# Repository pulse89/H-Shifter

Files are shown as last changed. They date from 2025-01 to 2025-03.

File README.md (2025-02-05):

# H-Pattern and Sequential Shifter

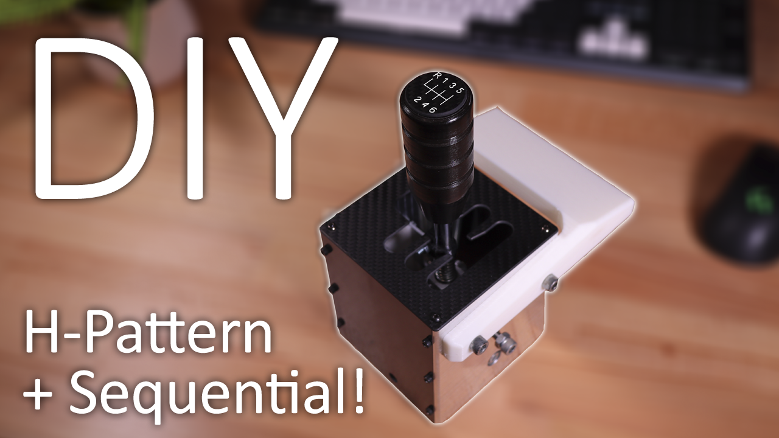
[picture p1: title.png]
H-Shifter


Link to the video: [https://youtu.be/RtLBD2DWTTg](https://youtu.be/AKZnvJ_tqVI)

I got sick of using the flappy paddles on my Logitech wheel so I decided to build my own H-Pattern and sequential shifter! All parts can be 3D printed!

I've included all the files in both STEP and STL format. If you decide to have the internals made in Aluminium like I did in the video, use the "Bearing Mount Alloy.STEP" file instead of the "Printed Bearing Block.STL".

You will also need to purchase the following parts:

2x 625 Bearings - https://www.aliexpress.com/item/1005004857666772.html

2x R4 Bearings - https://www.aliexpress.com/item/32929910901.html

4x 623 Bearings - https://www.aliexpress.com/item/1005004857666772.html

1x 10k 16mm Linear Potentiometer - https://www.aliexpress.com/item/1005006600576995.html

2x Micro Lever Switches (Handle 11.5mm) - https://www.aliexpress.com/item/1005005596552328.html

5mm Steel Ball - https://www.aliexpress.com/item/1005005656499702.html

4mm OD Spring - https://www.aliexpress.com/item/1005005402716572.html

13x30x1.4 Spring - https://www.aliexpress.com/item/1005006145869116.html

10x30x1 Extension Spring - https://www.aliexpress.com/item/1005006138122733.html

1x Arduino Pro Micro - https://www.aliexpress.com/item/1005006654641959.html

1x 10x140mm Hardened Steel Shaft - https://www.aliexpress.com/item/1005007573838689.html

If printing, you will also need:
16x M3x5x5 Threaded Inserts
2x M3x4x5 Threaded Inserts

You'll also need a variety of M3 screws, nuts and washers along with a couple of M5 washers for spacing out the bearings as shown in the video.

#### Electronics and Software

Wire the potentiometer output to A3, and the switches to D2 and D3.

When you first flash the code to your Arduino, change the debug variable to true and check the serial port for readings from your potentiometer. Copy values from each gate into the correct variables and then re-upload the code and verify the correct gears are being selected. Then change debug back to false and re-upload!

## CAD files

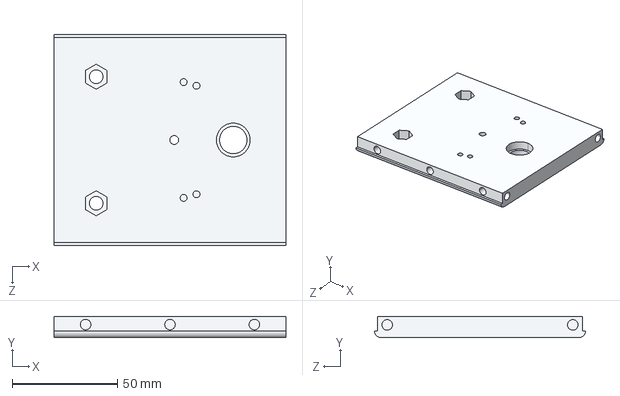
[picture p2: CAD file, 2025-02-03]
3D Files/STEP/Housing Side 2.STEP
110.0 x 10.0 x 100.0 mm

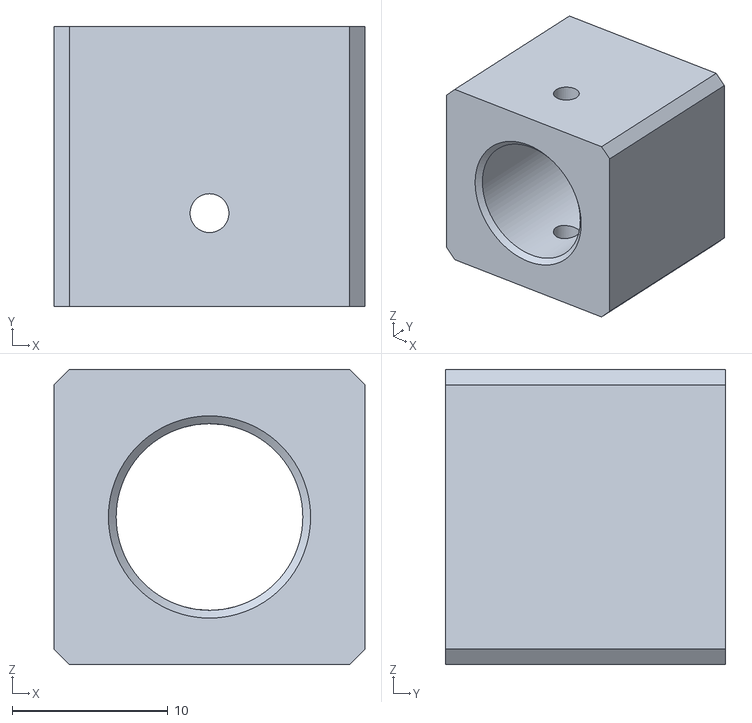
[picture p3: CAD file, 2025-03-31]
3D Files/STL/Bearing Mount Alloy v2.STL
20.0 x 18.0 x 19.0

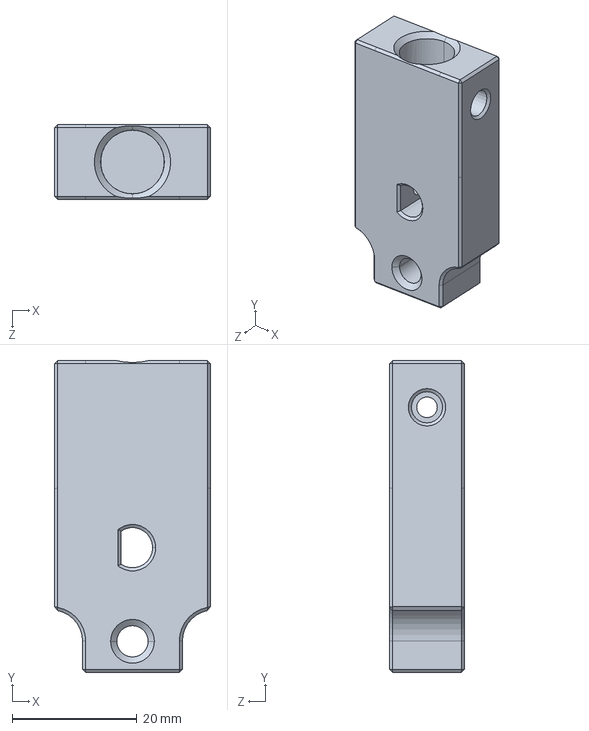
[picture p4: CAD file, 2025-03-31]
3D Files/SW/Shaft Pivot 3D Print.SLDPRT
25.0 x 50.0 x 12.0 mm

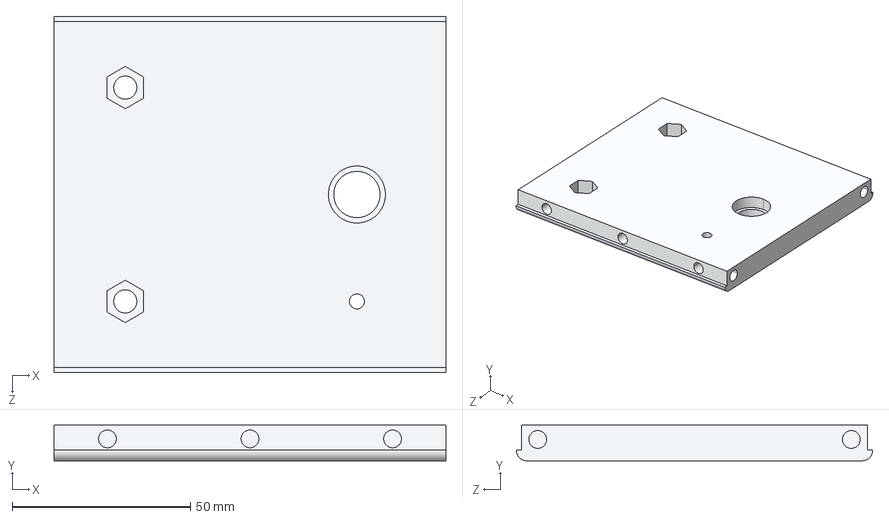
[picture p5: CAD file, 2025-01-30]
3D Files/STEP/Housing Side 1.STEP
110.0 x 10.0 x 100.0 mm

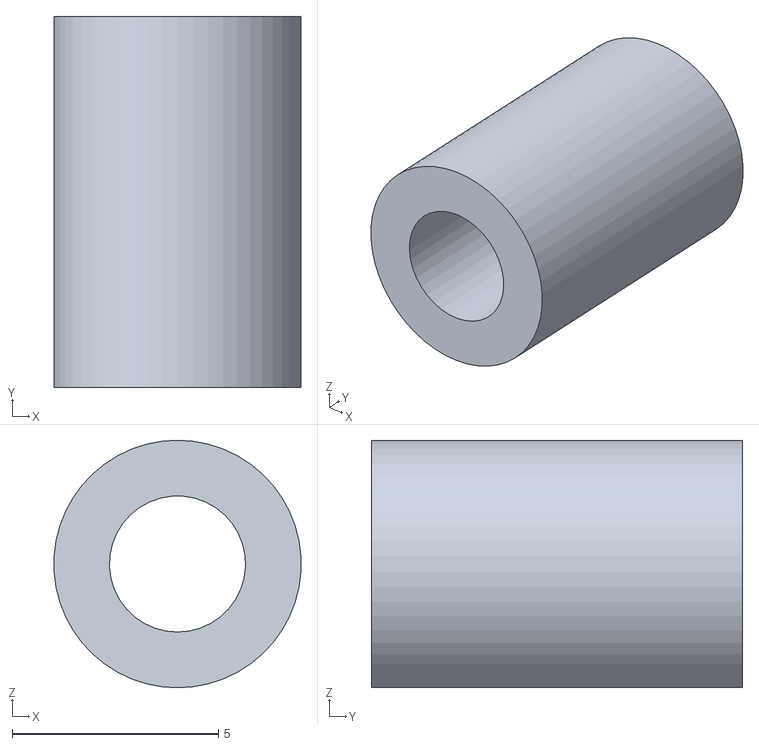
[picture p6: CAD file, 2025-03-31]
3D Files/STL/Spring Arm Spacer.STL
5.99 x 9.00 x 6.00

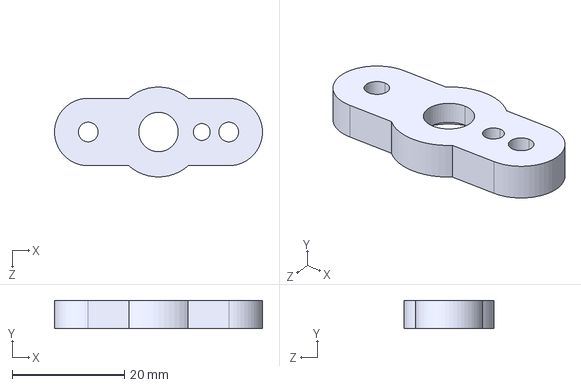
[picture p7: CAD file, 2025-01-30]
3D Files/STEP/Pot Mount.STEP
37.0 x 5.00 x 16.0 mm

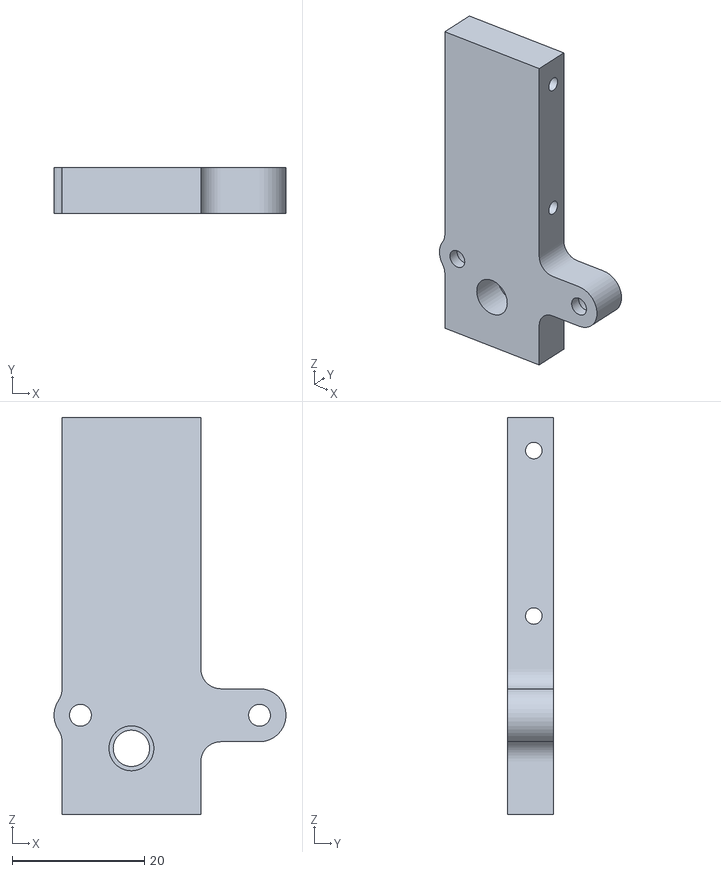
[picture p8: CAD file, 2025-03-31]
3D Files/STL/Shifter Spring End Plate v2.STL
35.0 x 7.00 x 60.0

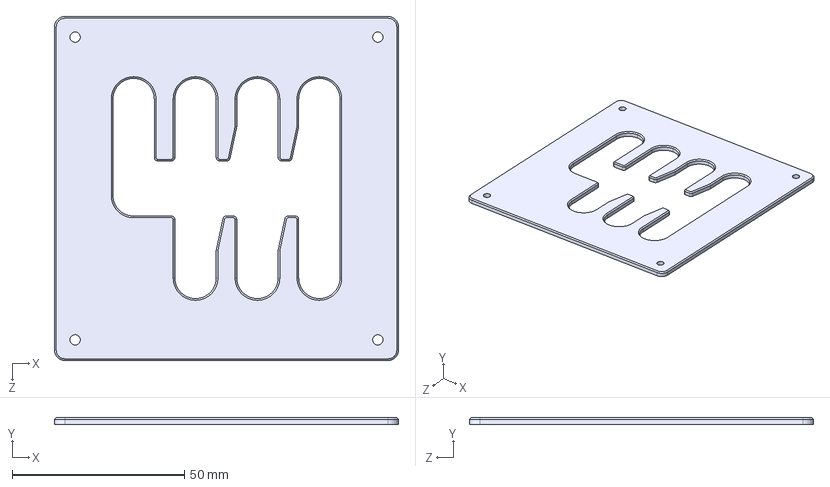
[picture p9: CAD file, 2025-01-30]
3D Files/STEP/Shifter Top Plate.STEP
100.0 x 2.00 x 100.0 mm

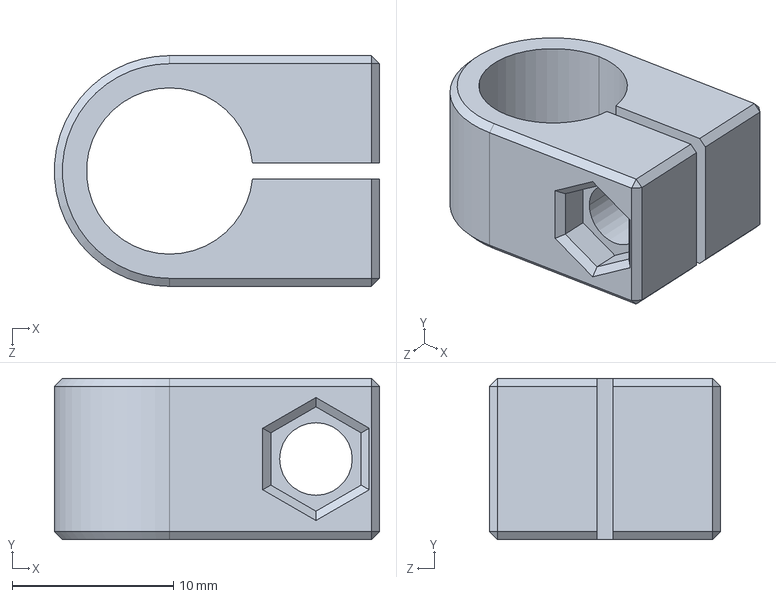
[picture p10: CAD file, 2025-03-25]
3D Files/SW/Shaft Clamp.SLDPRT
20.1 x 10.0 x 14.3 mm

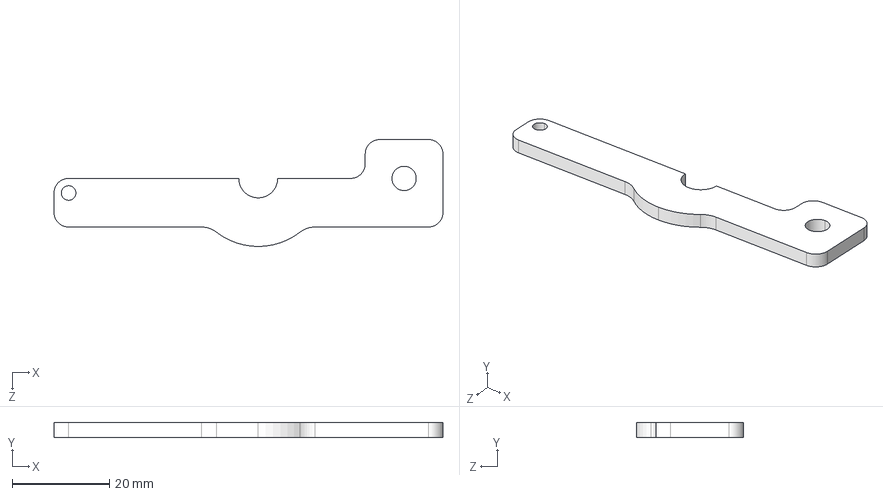
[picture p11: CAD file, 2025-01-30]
3D Files/STEP/Spring Arm.STEP
80.0 x 3.00 x 22.0 mm

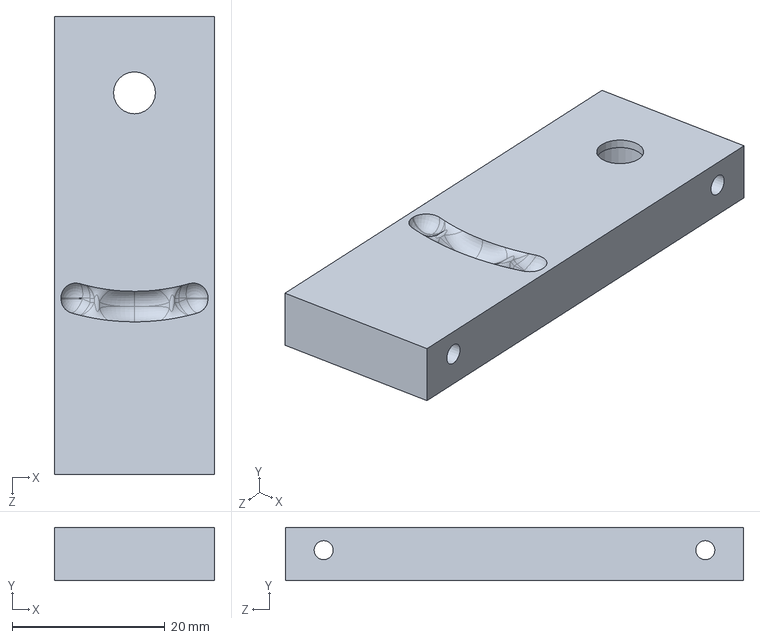
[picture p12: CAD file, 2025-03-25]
3D Files/SW/Shifter End Plate.SLDPRT
21.0 x 7.00 x 60.0 mm

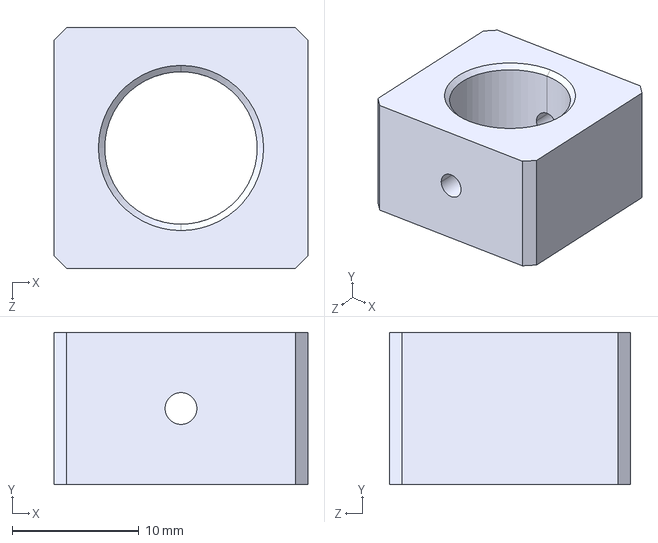
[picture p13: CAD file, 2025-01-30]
3D Files/STEP/Bearing Mount Alloy.STEP
20.0 x 12.0 x 19.0 mm

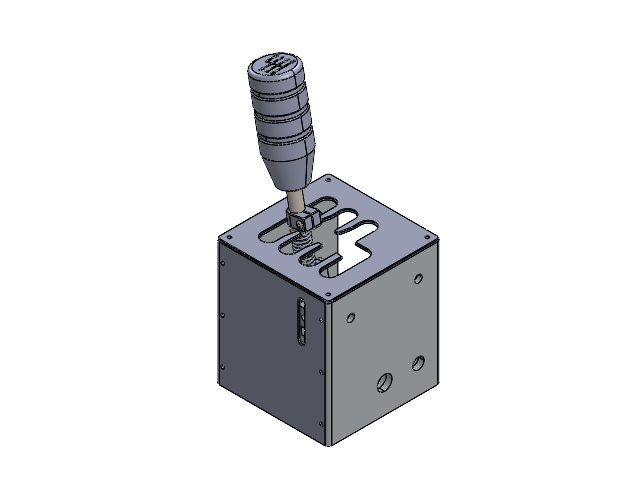
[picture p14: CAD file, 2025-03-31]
3D Files/Shifter Main Assembly.SLDASM
Housing Rear
Housing Side 1
Housing Side 2
Pot Mount
Bearing Mount 3D Printed
Shaft Clamp
Shifter Side Plate 1
Shifter Side Plate 2
Shifter Spring End Plate
Shaft Pivot 3D Print
Shifter End Plate
Shaft
623 Bearing x 2
Shifter Spring
R4ZZ Bearing x 2
R1212N_D-Shaft
Shaft Pivot Washer x 4
ISO 7380 - M3 x 16 - 16N
ISO - 4034 - M3 - N
Shifter Knob
Shifter Top Plate
Spring Arm
Spring Tensioner
Spring Arm Spacer

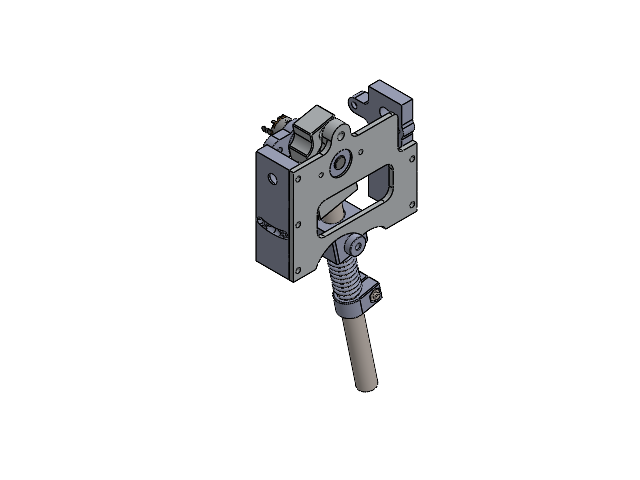
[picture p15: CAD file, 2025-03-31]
3D Files/Shifter Centre Assembly.SLDASM
Pot Mount
Bearing Mount 3D Printed
Shaft Clamp
Shifter Side Plate 1
Shifter Spring End Plate
Shaft Pivot 3D Print
Shifter End Plate
Shaft
623 Bearing x 2
Shifter Spring
R4ZZ Bearing x 2
R1212N_D-Shaft
Shaft Pivot Washer x 2
ISO 7380 - M3 x 16 - 16N
ISO - 4034 - M3 - N

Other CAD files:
3D Files/SW/Bearing Mount Alloy.SLDPRT
3D Files/SW/Bearing Mount 3D Printed.SLDPRT
3D Files/STL/Shaft Pivot 3D Print.STL
3D Files/STL/Bearing Mount 3D Printed.STL
3D Files/STEP/Desk Mount.STEP
3D Files/STEP/Housing Front.STEP
3D Files/STEP/Housing Rear.STEP
3D Files/STEP/Shaft Clamp.STEP
3D Files/STEP/Shaft Pivot.STEP
3D Files/STEP/Shifter End Plate.STEP
3D Files/STEP/Shifter Knob.STEP
3D Files/STEP/Shifter Side Plate 1.STEP
3D Files/STEP/Shifter Side Plate 2.STEP
3D Files/STEP/Shifter Spring End Plate.STEP
3D Files/STEP/Spring Tensioner.STEP
3D Files/STL/Desk Mount.STL
3D Files/STL/Housing Front.STL
3D Files/STL/Housing Rear.STL
3D Files/STL/Housing Side 1.STL
3D Files/STL/Housing Side 2.STL
3D Files/STL/PETG Bushing.STL
3D Files/STL/Pot Mount.STL
3D Files/STL/Printed Bearing Block.STL
3D Files/STL/Shaft Clamp v2.STL
3D Files/STL/Shaft Clamp.STL
3D Files/STL/Shaft Pivot Washer.STL
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

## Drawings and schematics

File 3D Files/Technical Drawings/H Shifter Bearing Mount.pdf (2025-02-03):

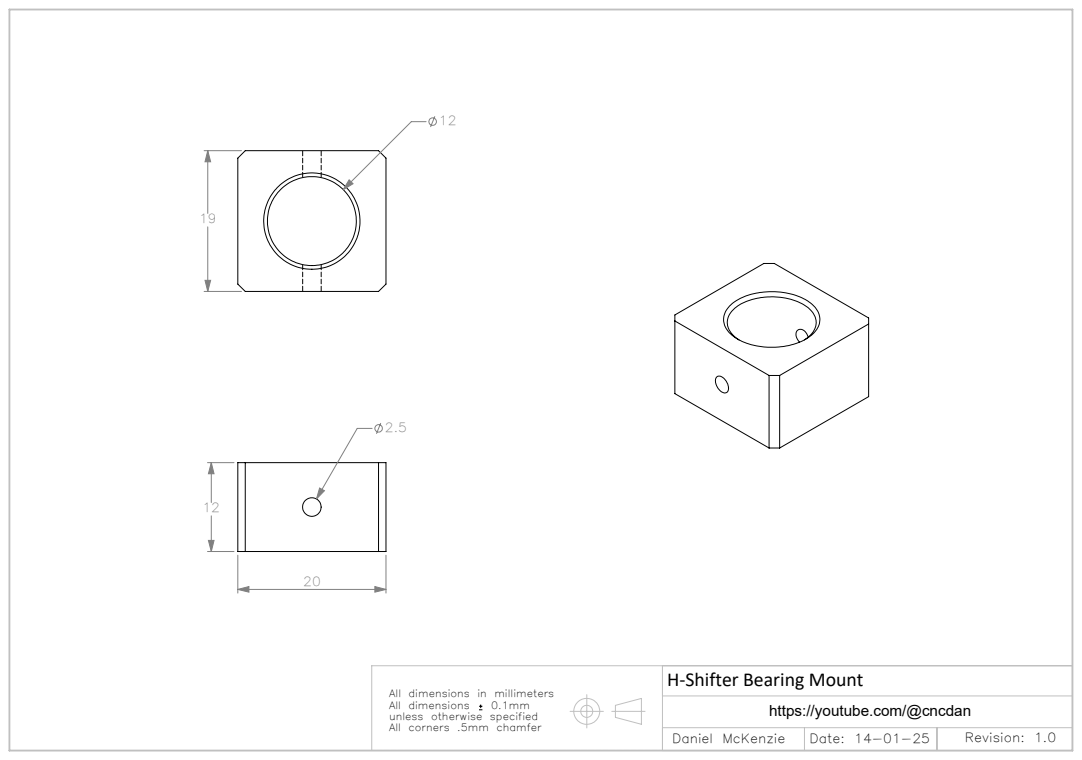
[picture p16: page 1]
Daniel McKenzie; Date: 14-01-25; Revision: 1.0; All dimensions

H-Shifter Bearing Mount

All dimensions in millimeters
unless otherwise specified
All corners .5mm chamfer

https://youtube.com/@cncdan

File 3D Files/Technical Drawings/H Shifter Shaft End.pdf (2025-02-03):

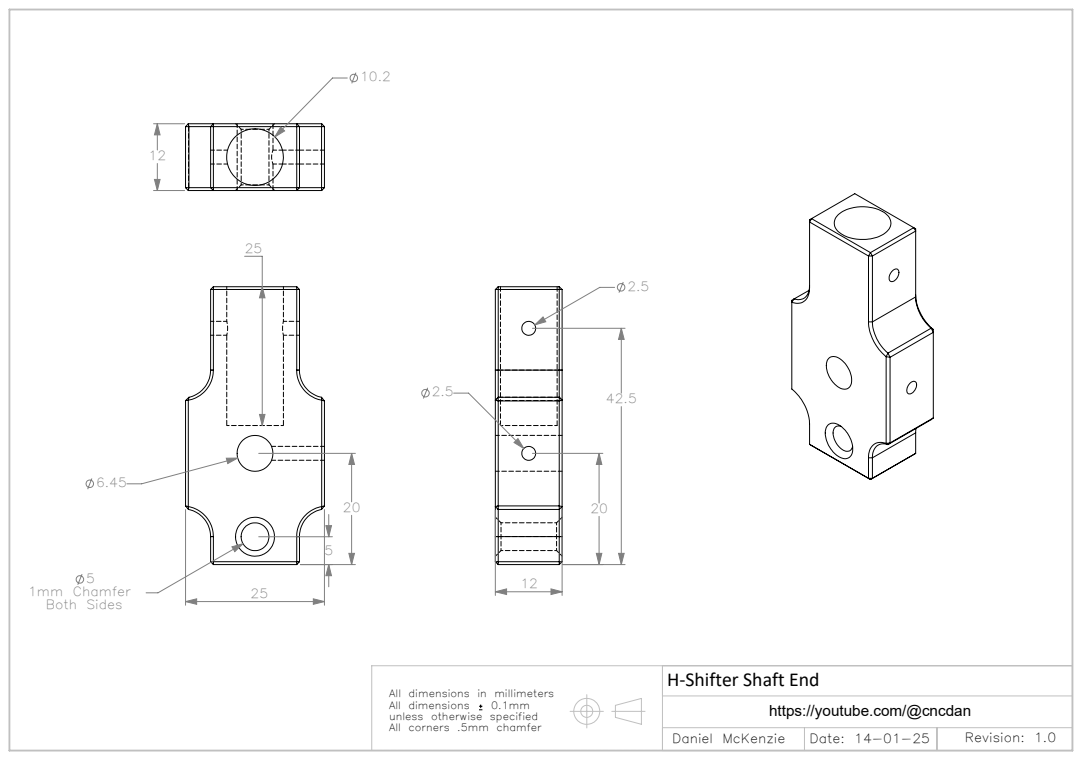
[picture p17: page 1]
1mm Chamfer Both Sides; Daniel McKenzie; Date: 14-01-25; Revision: 1.0; All dimensions

H-Shifter Shaft End

All dimensions in millimeters
unless otherwise specified
All corners .5mm chamfer

https://youtube.com/@cncdan

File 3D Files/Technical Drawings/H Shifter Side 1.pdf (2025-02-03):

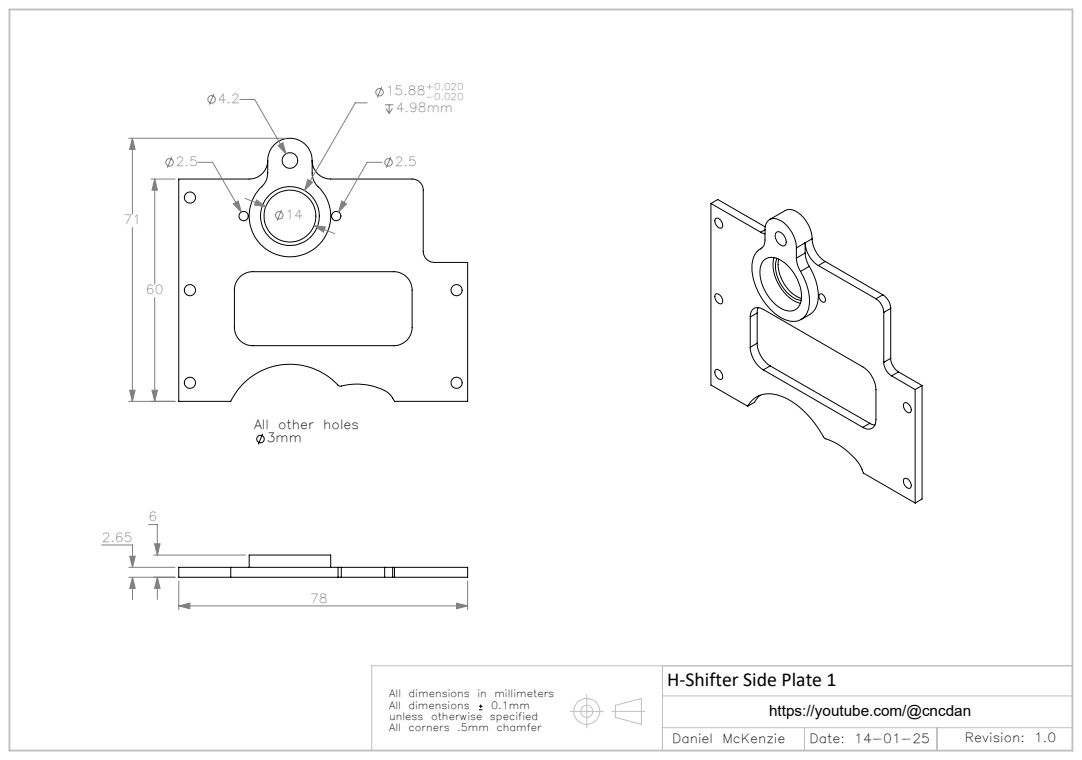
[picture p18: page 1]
Daniel McKenzie; Date: 14-01-25; Revision: 1.0; All dimensions

All other holes

H-Shifter Side Plate 1

All dimensions in millimeters
unless otherwise specified
All corners .5mm chamfer

https://youtube.com/@cncdan

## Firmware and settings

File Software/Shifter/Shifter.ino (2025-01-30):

#include "HID-Project.h"

int gearUp = 2; //Pin 2 for top row of gears
int gearDn = 3; //Pin 3 for bottom row of gears

//Change these values to match the values shown in debug for each gate.
int gateR = 222;
int gate12 = 183;
int gate34 = 145;
int gate56 = 106;

int gateDeadband = 10; //Adjust higher if analog signal is too noisey

int gateSelected;

int currentGear = 0;

bool debug = false; //Set to true to output potentiometer value and gear selected over serial.

void setup() {
  if(debug){
    Serial.begin(9600);
  }
  pinMode(gearUp, INPUT_PULLUP);
  pinMode(gearDn, INPUT_PULLUP);

  Gamepad.begin();
}

void loop() {
  gateSelected = analogRead(A3); //Read Potentiometer

  if(!digitalRead(gearUp)){ //Reverse,First,Third or fifth selected
    if(gateSelected < gate56 + gateDeadband){
      Gamepad.press(5);
      currentGear = 5;
    } else if(gateSelected < gate34 + gateDeadband && gateSelected > gate34 - gateDeadband){
      Gamepad.press(3);
      currentGear = 3;
    } else if(gateSelected < gate12 + gateDeadband && gateSelected > gate12 - gateDeadband){
      Gamepad.press(1);
      currentGear = 1;
    } else if(gateSelected < gateR + gateDeadband && gateSelected > gateR - gateDeadband){
      Gamepad.press(7);
      currentGear = 7;
    }
  } else if(!digitalRead(gearDn)){ //Second, fourth or sixth selected
    if(gateSelected < gate56 + gateDeadband){
      Gamepad.press(6);
      currentGear = 6;
    } else if(gateSelected < gate34 + gateDeadband && gateSelected > gate34 - gateDeadband){
      Gamepad.press(4);
      currentGear = 4;
    } else if(gateSelected < gate12 + gateDeadband && gateSelected > gate12 - gateDeadband){
      Gamepad.press(2);
      currentGear = 2;
    } 
  } else {
    Gamepad.releaseAll();
  }

  if(debug){
    Serial.print("Current Potentiometer Value: ");
    Serial.println(gateSelected);
    Serial.print("Gear Selected: ");
    Serial.println(currentGear);
  }

  Gamepad.write();
}

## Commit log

2025-01-30 Added 3D files
    [Bearing Mount Alloy.STEP, Desk Mount.STEP, Desk Mount.STL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]
2025-02-03 Update Housing Side 2.STL
    [Housing Side 2.STL]
2025-02-03 Update Housing Side 2.STEP
    [Housing Side 2.STEP]
2025-03-24 Added Assembly
    Converted STP files to SW Part files
    Added Bearing models
    Added Main Spring model
    Added 10k Pot model
    TODO: Add tensionerspring
    TODO: Add microswitches
    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
    [623 Bearing.SLDPRT, Bearing Mount Alloy.SLDPRT, Housing Front.SLDPRT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]
2025-03-25 Updates to various
    Bearing Mount - Added 6 mm in height to prevent catching when at maximum
    Shaft Clamp - made cut out for M3 nut, remove need to use nut driver
    Shaft Pivot - Added 3D printed version; added material for d-shaft, no longer relying solely on lock screw to rotate pot shaft, added chamfers on screw holes (I was using self-tapping screws, makes it easier to start the threads)
    Shifter End Plate - Expanded M5 hole to be able to use threaded inserts (also added 1 mm material and then a 1 mm thick hard stop), changes mounting holes to DIA2.5 mm to accommodate self tapping screws
    Shifter Spring End Plate - Expanded M5 hole to be able to use threaded inserts (also added 1 mm materi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
    [Bearing Mount Alloy.SLDPRT, Shaft Clamp.SLDPRT, Shaft Pivot 3D Print.SLDPRT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]
2025-03-31 Mods
    Bearing Mount 3D Printed - Added length to the 3D printed version
    Shaft Pivot 3D Print - Added material to use threaded inserts, opened up D-shaft hole
    [Bearing Mount 3D Printed.SLDPRT, Bearing Mount 3D Printed.STL, Bearing Mount Alloy v2.STL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]
